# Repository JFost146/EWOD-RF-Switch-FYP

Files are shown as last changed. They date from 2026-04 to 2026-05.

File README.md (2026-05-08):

# Final Year Project  
## MEng Electrical and Electronic Engineering  
### Jack Foster — University of Birmingham

This repository contains the work completed for my final year MEng project at the University of Birmingham.

The project focuses on the development of an **electrowetting-on-dielectric (EWOD) circuit** designed to actuate a liquid droplet into a waveguide channel, where the liquid acts as part of an **RF switch**.

---

## Licence

This project is released under the **GNU General Public License v3.0**.

You are free to use, modify, and distribute the software and associated project files under the terms of the GPLv3. Any redistributed or modified versions must also comply with the GPLv3 terms.

A full copy of the licence is provided in the [`LICENSE`](license.txt) file.

Parts of this project are derived from or inspired by the GaudiLabs OpenDrop project and Nick de Smith’s Nixie high-voltage switching PSU. Please refer to the acknowledgements section for the original sources.

---

## Project Overview

The repository includes:

- KiCad circuit schematics and PCB design files
- Electrode board designs for EWOD testing
- Arduino-based control software
- RF switch simulation and measurement results
- Supporting notes and design references

---

## Circuit Basics

The `Circuit` folder contains the **KiCad 9.0** schematics, footprints, and manufacturing files used for the PCB.

The boards used in the project were manufactured by **JLCPCB** at approximately **£30 per board**. These boards used **ENIG plating** to optimise coupling between electrodes for EWOD operation. However, the design would likely still work with the cheaper **HASL** finish.

---

## Microcontroller and Software

The circuit was tested using a **Seeed Studio XIAO nRF52840**:

[Seeed Studio XIAO nRF52840 Documentation](https://wiki.seeedstudio.com/XIAO_BLE/)

The board should also be compatible with other microcontroller boards, as the controllable components operate using:

- `3V3`
- Clock signal
- Latch / chip-select signal

The controllable components are:

- Digital potentiometer
- High-voltage switch controller

The control code is written for **Arduino** and can be found in the `Software` folder.

---

## Board Setup and EWOD Testing

To use the board:

1. Snap off the electrode boards.
2. Solder all required components.
3. Connect an electrode board using fly-wires.
4. Add a hydrophobic oil layer to the electrodes.  
   - Silicone oil, **5 cSt**, is preferred.
5. Place a dielectric layer on top of the oil.  
   - Cling film can be used.
6. Add another oil layer on top of the dielectric.
7. Place the droplet above an electrode.
8. Observe the EWOD actuation.

---

## Notes and Testing Observations

- The potentiometer can be bypassed using the `R_pot_sub` resistor pads with either:
  - a `0 Ω` resistor, or
  - a solder bridge.

- Successful tests were proven at maximum voltage output, with the potentiometer set to `0 Ω`.

- EWOD actuation is likely to work at voltages of **200 V or higher**.

- The best EWOD results were achieved using the rectangular electrodes with droplets whose diameter was approximately equal to, or larger than, the width of one electrode.

- The board design is derived from the GaudiLabs OpenDrop board:  
  [GaudiLabs OpenDrop](https://www.gaudi.ch/OpenDrop/)

- The DC-DC converter design originates from Nick de Smith’s Nixie high-voltage switching PSU:  
  [Nick de Smith Nixie PSU](https://www.nick.desmith.net/Electronics/NixiePSU.html)

---

## Board Specifications

| Parameter | Value |
|---|---|
| Input voltage | 5 V |
| Input current at maximum output | 0.16 A |
| Theoretical input range | 4.5 V to 16 V |
| Electrode output voltage range | 50 V to 290 V |
| Electrode output current range | 2.3 µA to 13.2 µA |
| Number of electrode designs | 7 |
| Minimum tested standalone output from XIAO nRF52840 USB input  | 50 V |

---

## RF Switch Investigation

The `Liquid Switch Tests` results contain:

- CST simulation results
- VNA measurement results
- RF switch response data for different liquids

These results investigate the behaviour of an RF switch when closed using various liquid materials.

---

## Switch Link

Add switch link here.

---

## Acknowledgements

This project builds on open-source and publicly documented work from:

- [GaudiLabs OpenDrop](https://www.gaudi.ch/OpenDrop/)
- [Nick de Smith’s Nixie HV Switching PSU](https://www.nick.desmith.net/Electronics/NixiePSU.html)

---

## Author

**Jack Foster**  
MEng Electrical and Electronic Engineering  
University of Birmingham

## Project Supervisor

**Prof. Yi Wang**  
Department of Electronic, Electrical and Systems Engineering  
University of Birmingham

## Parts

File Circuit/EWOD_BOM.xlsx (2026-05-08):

Component | Designator | Value | Quantity | Price | Link | Total
478-KGM21NR71H104KTCT-ND | C2,C3 | 100nF | 2 | £0.07 | https://www.digikey.com/en/products/detail/kyocera-avx-components-corporation/KGM21NR71H104KT/564427?curr=gbp | £0.14
CL31A106KBHNNNE | C5 | 10uF | 1 | £0.27 | https://www.digikey.com/en/products/detail/samsung-electro-mechanics-america-inc/CL31A106KBHNNNE/3890962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 | £0.27
875105344010 | C1 | 100uF | 1 | £0.50 | https://www.digikey.com/en/products/detail/wurth-electronics-inc/875105344010/5147976?curr=gbp | £0.50
CDRH125/LDNP-101MC | L1 | 100uH | 1 | £0.82 | https://www.digikey.com/en/products/detail/sumida-america-inc/CDRH125-LDNP-101MC/1879027?curr=gbp | £0.82
RC0805JR-078K2L | R1 | 8k | 1 | £0.07 | https://www.digikey.com/en/products/detail/yageo/RC0805JR-078K2L/731320?curr=gbp | £0.07
CRCW080510K0FKEA | R5 | 10k | 1 | £0.07 | https://www.digikey.com/en/products/detail/vishay-dale/CRCW080510K0FKEA/1180897?curr=gbp | £0.07
RMCF1206JT22M0 | R3,R4,R8,R11 | 22M | 4 | £0.08 | https://www.digikey.com/en/products/detail/stackpole-electronics-inc/RMCF1206JT22M0/7906919?curr=gbp | £0.32
WSL2010R1000FEA18 | RSENSE1 | 0R100 | 1 | £0.76 | https://www.digikey.com/en/products/detail/vishay-dale/WSL2010R1000FEA18/713471?curr=gbp | £0.76
CC1812KKX7RYBB104 | C6 | 100nF, 250V | 1 | £0.63 | https://www.digikey.com/en/products/detail/yageo/CC1812KKX7RYBB104/8025658?curr=gbp | £0.63
KTR10EZPF1604 | R2 | 1M6 | 1 | £0.14 | https://www.digikey.com/en/products/detail/rohm-semiconductor/KTR10EZPF1604/1983963?curr=gbp | £0.14
AEH10104R7M250R | C4 | 4u7, 250V | 1 | £0.49 | https://www.digikey.com/en/products/detail/kyocera-avx-components-corporation/AEH10104R7M250R/21822541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 | £0.49
Xiao nRF52840 | Microcontroller1 | Conn_01x08 | 1 | £9.50 | https://www.google.com/aclk?co=1&cce=1&sig=AOD64_0QL7spy-WVdq1LHppbR7jBd_PUpQ&ctype=5&q=&adurl= | £9.50
625-ES2F-E3 | D1 | ES2F | 1 | £0.60 | https://www.digikey.com/en/products/detail/vishay-general-semiconductor-diodes-division/ES2F-E3-52T/1091575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 | £0.60
HV513WG-G | U2 | HV513 | 1 | £3.10 | https://www.digikey.com/en/products/detail/microchip-technology/HV513WG-G/4902648?curr=gbp | £3.10
MAX1771CPA | U1 | MAX1771ESA | 1 | £4.70 | https://www.digikey.co.uk/en/products/detail/analog-devices-inc-maxim-integrated/MAX1771CPA/1130157 | £4.70
MCP41050T-I/SN | U26 | MCP41050 | 1 | £1.40 | https://www.digikey.com/en/products/detail/microchip-technology/MCP41050T-I-SN/9923681?curr=gbp | £1.40
IRF644PBF-ND | T1 | TK560P60Y | 1 | £1.88 | https://uk.rs-online.com/web/p/mosfets/5429305?cm_mmc=aff2-_-uk-_-octopart-_-5429305-_-instock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 | £1.88
 |  |  |  |  |  | £25.39
 |  |  |  |  | After VAT | £30.47
PCB (per board with delivery) |  |  | 1 | £28.00 | https://jlcpcb.com | £58.47

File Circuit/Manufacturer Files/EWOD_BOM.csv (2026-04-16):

Comment | Qty | Designator | Footprint | LCSC Part Number | Manufacturer UK | Manufacturer Part Number
0 Ohms | 1 | R_pot_sub1 | - | -
100nF | 2 | C2,C3 | 0805 | C38141 | Digikey | 478-KGM21NR71H104KTCT-ND
10uF | 1 | C5 | 1206 | C1849 | Digikey | CL31A106KBHNNNE
100uF | 1 | C1 | Capacitor_SMD:CP_Elec_6.3x5.4_Nichicon | C2161820 | Digikey | 875105344010
100uH | 1 | L1 | CDRH125101MC | C212268 | Digikey | CDRH125/LDNP-101MC
8k | 1 | R1 | 0805 | C413197 | Digikey | P0805Z8001FNT
10k | 1 | R5 | 0805 | C22356686 | Digikey | CRCW080510K0FKEA
22M, 250 V | 4 | R3,R4,R8,R11 | 1206 | C41755 | Digikey | RMCF1206JT22M0
0R100, 1.5 A | 1 | RSENSE1 | 2010 | C159215 | Digikey | WSL2010R1000FEA18
100nF, 250V | 1 | C6 | 1812 | C304034 | Digikey | CC1812KKX7RYBB104
1M6, 250 V | 1 | R2 | 0805 | C723463 | Digikey | KTR10EZPF1604
4u7, 250V | 1 | C4 | Capacitor_SMD:CP_Elec_10x10.5 | C5549292 | Digikey | AEH10104R7M250R
Conn_01x02 | 7 | J1,J2,J8,J9,J10,J11,J12 | - | -
Conn_01x02 | 1 | J7 | - | -
Conn_01x07 | 2 | Power_In1,Power_In2 | - | -
Conn_01x08 | 1 | Microcontroller1 | - | -
Electrode 2 | 5 | U4,U11,U12,U13,U14 | - | -
Electrode 2 | 4 | U9,U23,U24,U25 | - | -
Electrode 2 | 4 | U15,U16,U17,U18 | - | -
Electrode 2 | 4 | U19,U20,U21,U22 | - | -
Electrode 2 | 4 | U27,U28,U29,U30 | - | -
Electrode 2 | 4 | U31,U32,U33,U34 | - | -
Electrode 3 | 1 | U5 | - | -
Electrode 6 | 1 | U8 | - | -
Electrode 8 | 1 | U10 | - | -
Diode ES2F, 300 V 2 A | 1 | D1 | DIOM5436X244N | C222525 | Mouser | 625-ES2F-E3
Ground Ref | 1 | U7 | - | -
HV513 | 1 | U2 | Package_SO:SOP-24_7.5x15.4mm_P1.27mm | C631624 | Digikey | HV513WG-G
MAX1771ESA | 1 | U1 | PowerIntegrations_PDIP-8 | C3191535 | RS | MAX1771CPA
MCP41050 | 1 | U26 | Package_SO:SOIC-8_3.9x4.9mm_P1.27mm | C623335 | Digikey | MCP41050T-I/SN
MountingHole | 14 | H8,H9,H10,H11,H12,H13,H14,H15,H16,H17,H18,H19,H20,H21 | - | -
MouseBites | 7 | H1,H2,H3,H4,H5,H6,H7 | - | -
On Pad | 1 | U6 | - | -
Power Pad | 1 | U3 | - | -
SW_SPDT | 1 | SW2 | - | -
Test Pad | 1 | U35 | - | -
TK560P60Y | 1 | T1 | Package_TO_SOT_THT:TO-220-3_Vertical | C469331 | Digikey | IRF644PBF-ND

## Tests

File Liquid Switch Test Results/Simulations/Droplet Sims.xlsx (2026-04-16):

Freq (GHz) | EGaIn, S11 | EGaIn, S21 | NaOH 0.1M, S11 | NaOH 0.1M, S21 | NaOH 0.5M, S11 | NaOH 0.5M, S21 | Water, S11 | Water, S21 | Closed, S11 | Closed, S21
0.01 | -0.000376655211 | -82.24116738 | -13.99641831 | -1.930987513 | -4.393044365 | -8.025012248 | -13.59804848 | -2.033075431 | -92.21690954 | -0.0001995270421
0.01999 | -0.000659199666 | -76.52338692 | -13.98466043 | -1.93139531 | -4.393074722 | -8.025206264 | -13.58557533 | -2.033878227 | -90.51732778 | -0.00081709787
0.02998 | -0.000920427591 | -73.12841517 | -13.96338379 | -1.932486234 | -4.392912318 | -8.025519188 | -13.56503447 | -2.035115462 | -89.09809974 | -0.001413145426
0.03997 | -0.001170434871 | -70.70007646 | -13.93341964 | -1.934063492 | -4.392603916 | -8.025895763 | -13.53650574 | -2.036782243 | -87.89210273 | -0.001988137113
0.04996 | -0.001413237737 | -68.80647088 | -13.8951471 | -1.936080485 | -4.3921554 | -8.026329239 | -13.50019209 | -2.038872466 | -86.85141026 | -0.002542538794
0.05995 | -0.001650924175 | -67.25332851 | -13.8489079 | -1.938515929 | -4.391568397 | -8.026817909 | -13.45635354 | -2.041378785 | -85.94190356 | -0.003076814639
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

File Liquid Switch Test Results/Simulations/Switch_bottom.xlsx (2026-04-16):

Freq (GHz) | GaAs, S11 | GaAs, S21 | NaOH 0.1M, S11 | NaOH 0.1M, S21 | Water, S11 | Water, S21 | Water Distilled, S11 | Water Distilled, S21 | Closed, S11 | Closed, S21
0.01 | -54.93709802 | -0.0002809672602 | -11.62602498 | -2.64166928 | -11.25891555 | -2.776195634 | -39.72329924 | -0.0005303563871 | -75.41402262 | -0.0001983249939
0.01999 | -49.27840449 | -0.0005304665452 | -11.61680169 | -2.642487383 | -11.25361269 | -2.776760838 | -33.71191424 | -0.00169013826 | -72.93053185 | 0
0.02998 | -45.83041074 | -0.000810645648 | -11.60136426 | -2.643738667 | -11.2424969 | -2.777790795 | -30.19526843 | -0.003797075019 | -70.33123351 | 0
0.03997 | -43.35782394 | -0.001121263951 | -11.57978102 | -2.645423073 | -11.22557044 | -2.779285651 | -27.70139447 | -0.006849035442 | -68.11174618 | 0
0.04996 | -41.43117539 | -0.001462085401 | -11.55215091 | -2.647540351 | -11.202867 | -2.781245308 | -25.76855317 | -0.01084318547 | -66.2546239 | -9.643274666e-16
0.05995 | -39.85309248 | -0.001832878575 | -11.51860199 | -2.650090057 | -11.17445114 | -2.783669425 | -24.19098825 | -0.01577599514 | -64.67918868 | 0
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

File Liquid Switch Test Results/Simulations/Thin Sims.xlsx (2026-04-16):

Freq (GHz) | EGaIn, S11 | EGaIn, S21 | NaOH 0.1M, S11 | NaOH 0.1M, S21 | NaOH 0.5M, S11 | NaOH 0.5M, S21 | Water, S11 | Water, S21 | Closed, S11 | Closed, S21
0.01 | -0.0002127651725 | -83.34633011 | -14.18135866 | -1.888299912 | -4.484407936 | -7.888869163 | -13.79624295 | -1.986299744 | -92.21690954 | -0.0001995270421
0.01999 | -0.0004240735189 | -77.50630795 | -14.17187284 | -1.888804342 | -4.484445048 | -7.889098277 | -13.78676481 | -1.986824623 | -90.51732778 | -0.00081709787
0.02998 | -0.0006346349216 | -74.11918099 | -14.15561943 | -1.889559699 | -4.484364335 | -7.889373459 | -13.77110999 | -1.987614254 | -89.09809974 | -0.001413145426
0.03997 | -0.0008446135549 | -71.73188525 | -14.13286771 | -1.890564659 | -4.484176411 | -7.889687112 | -13.74927227 | -1.988665417 | -87.89210273 | -0.001988137113
0.04996 | -0.001054106988 | -69.89039533 | -14.10375809 | -1.891818957 | -4.483882651 | -7.890038297 | -13.72134602 | -1.98997739 | -86.85141026 | -0.002542538794
0.05995 | -0.001263181905 | -68.39298722 | -14.06843898 | -1.893322169 | -4.483483483 | -7.890426767 | -13.68745967 | -1.991549689 | -85.94190356 | -0.003076814639
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

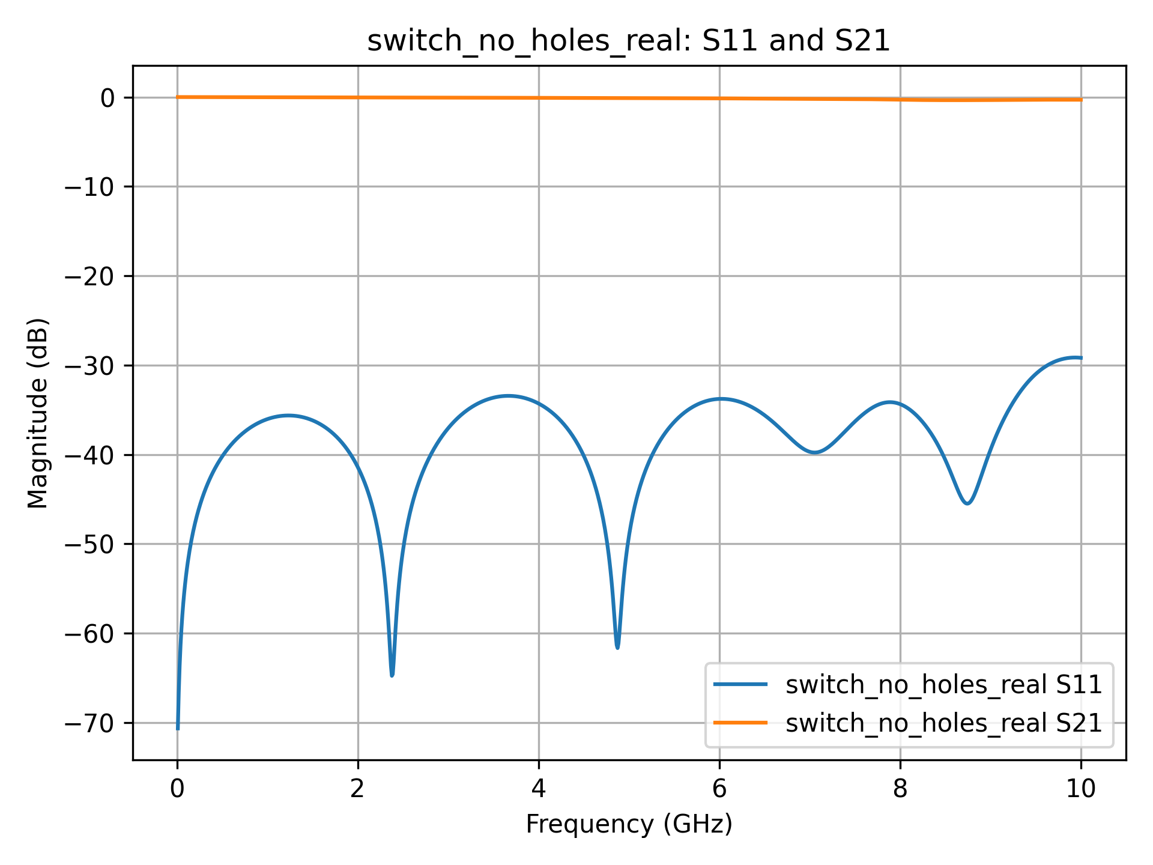
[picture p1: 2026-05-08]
Liquid Switch Test Results/Simulations/Figures/switch_no_holes_real_S11_S21_plot.png

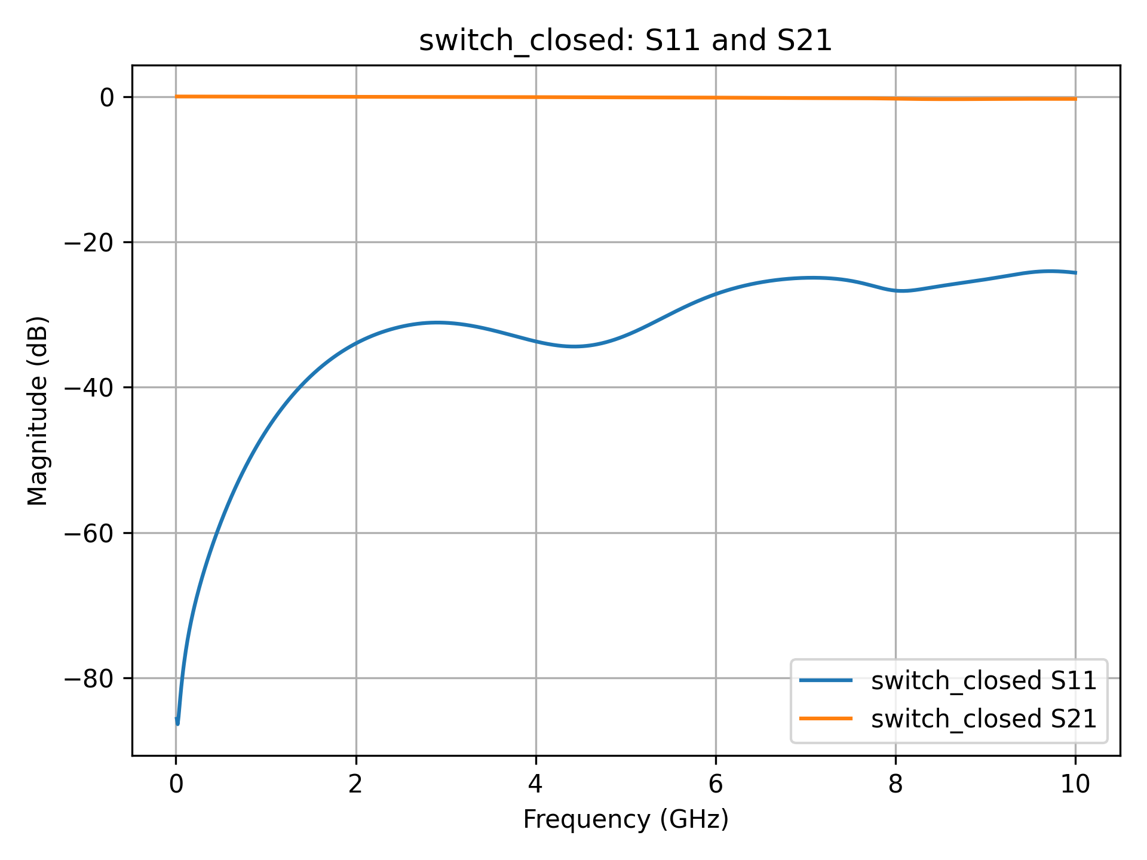
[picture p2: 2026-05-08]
Liquid Switch Test Results/Simulations/Figures/switch_closed_S11_S21_plot.png

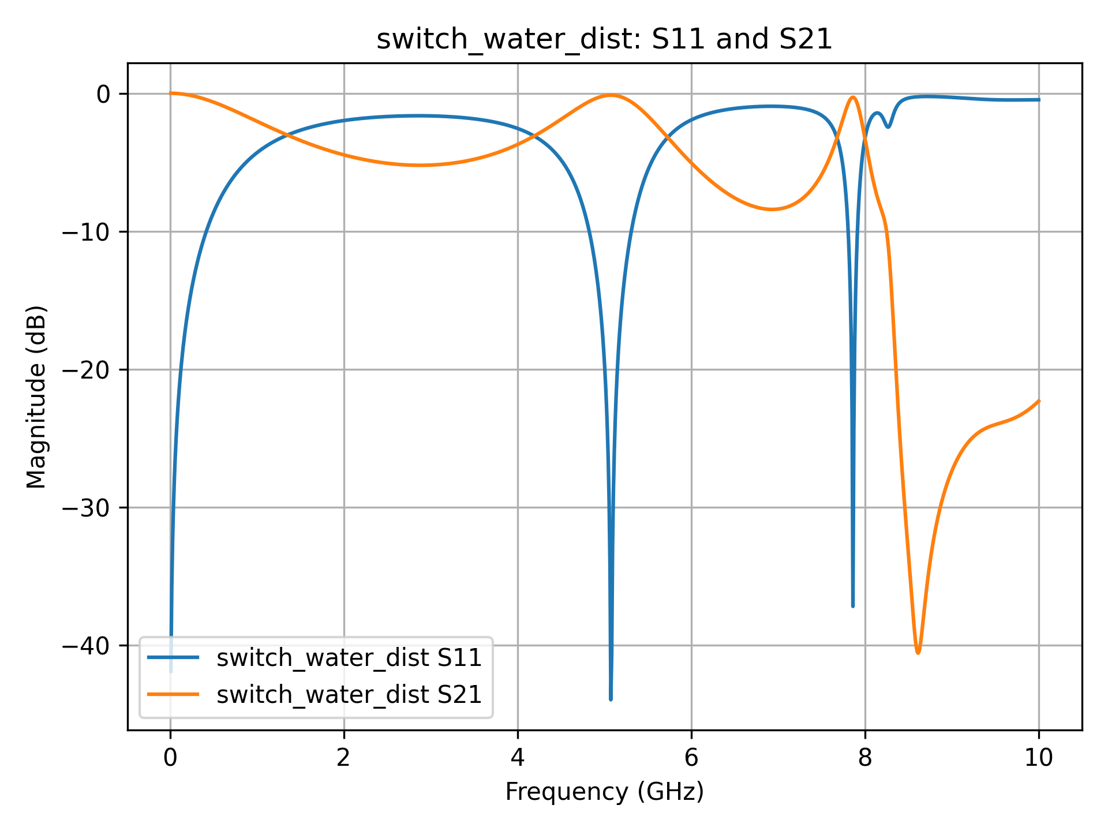
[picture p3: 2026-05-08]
Liquid Switch Test Results/Simulations/Figures/switch_water_dist_S11_S21_plot.png

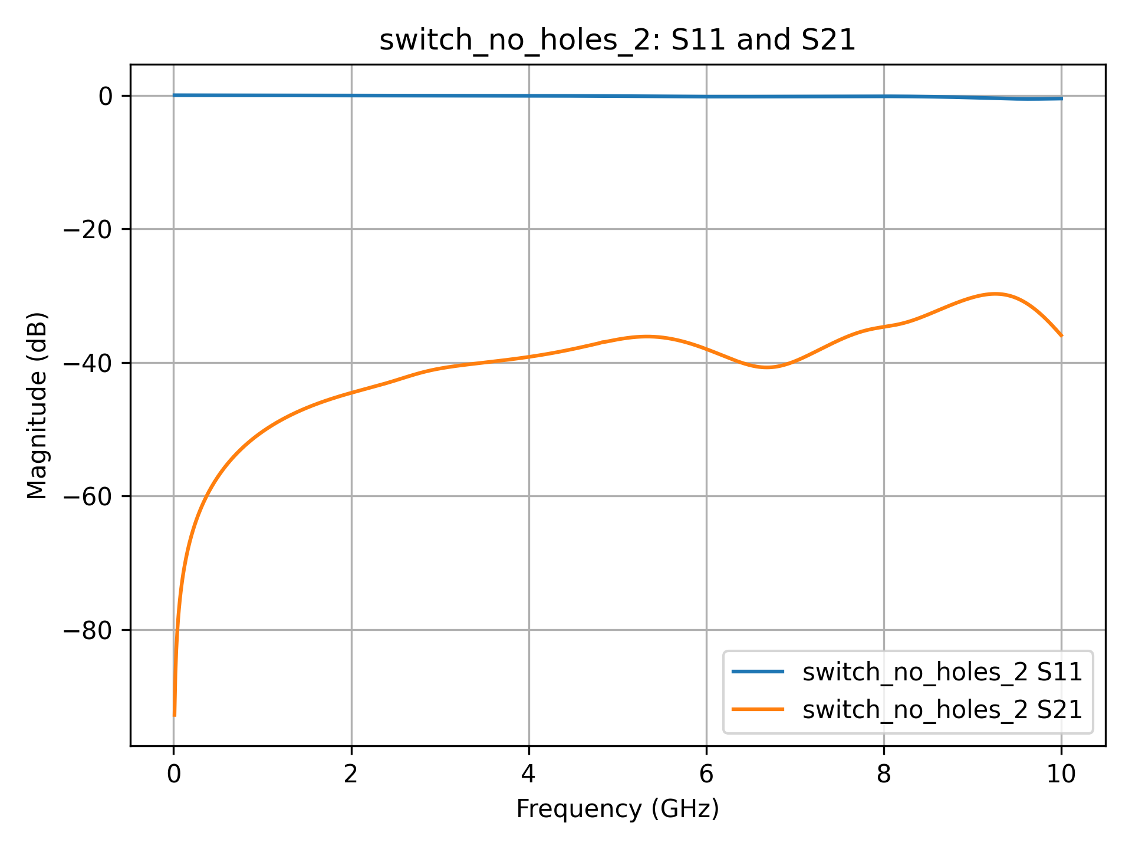
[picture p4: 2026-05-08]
Liquid Switch Test Results/Simulations/Figures/switch_no_holes_2_S11_S21_plot.png

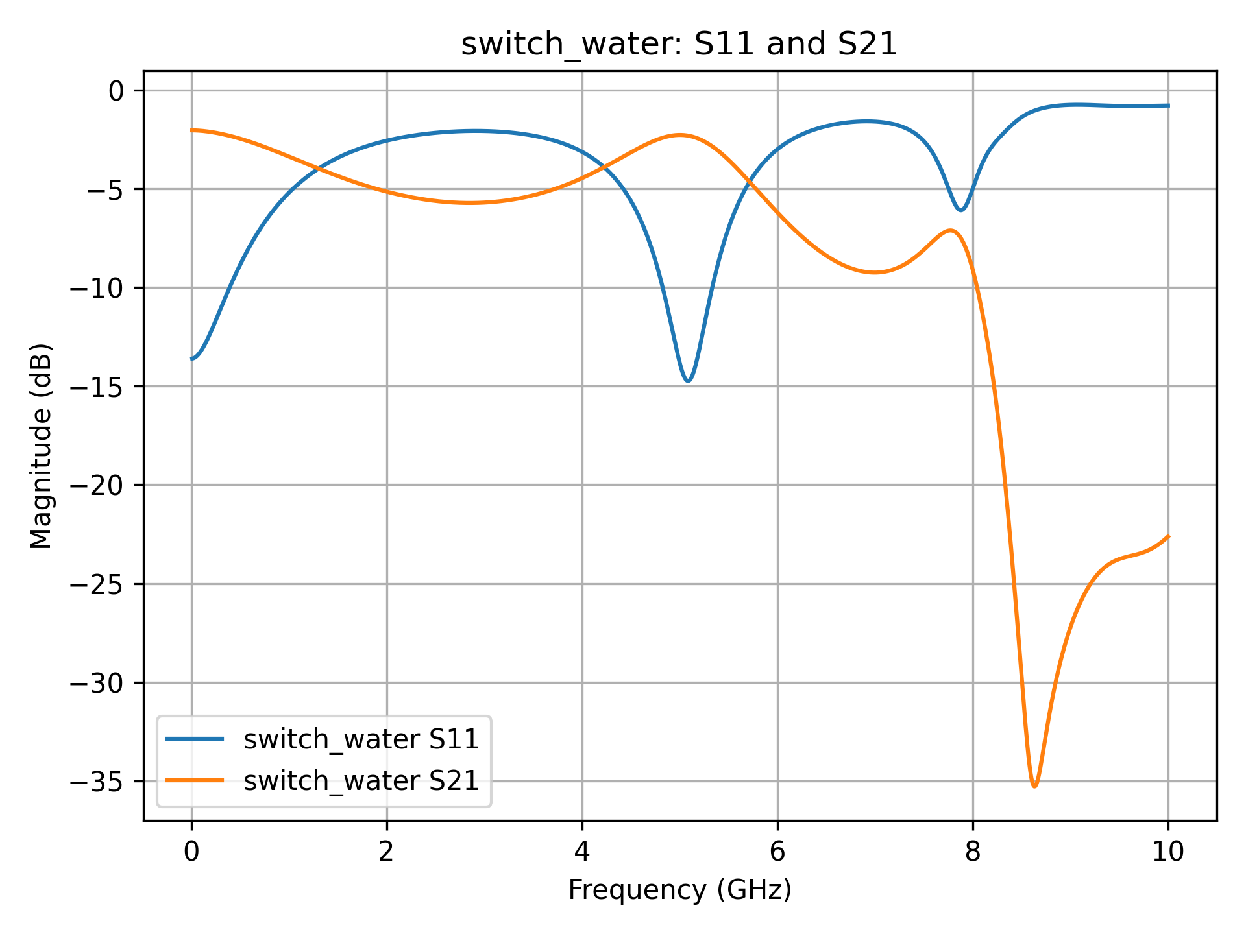
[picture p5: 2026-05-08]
Liquid Switch Test Results/Simulations/Figures/switch_water_S11_S21_plot.png

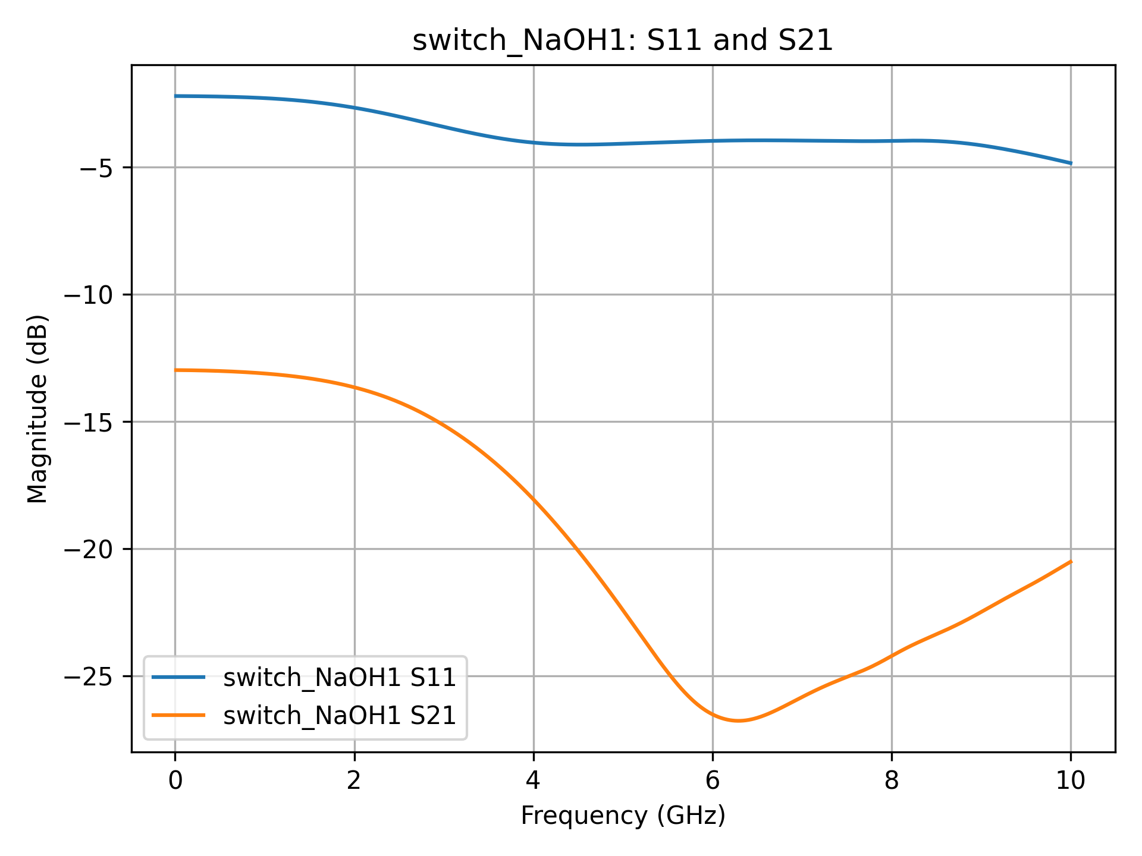
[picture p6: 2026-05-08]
Liquid Switch Test Results/Simulations/Figures/switch_NaOH1_S11_S21_plot.png

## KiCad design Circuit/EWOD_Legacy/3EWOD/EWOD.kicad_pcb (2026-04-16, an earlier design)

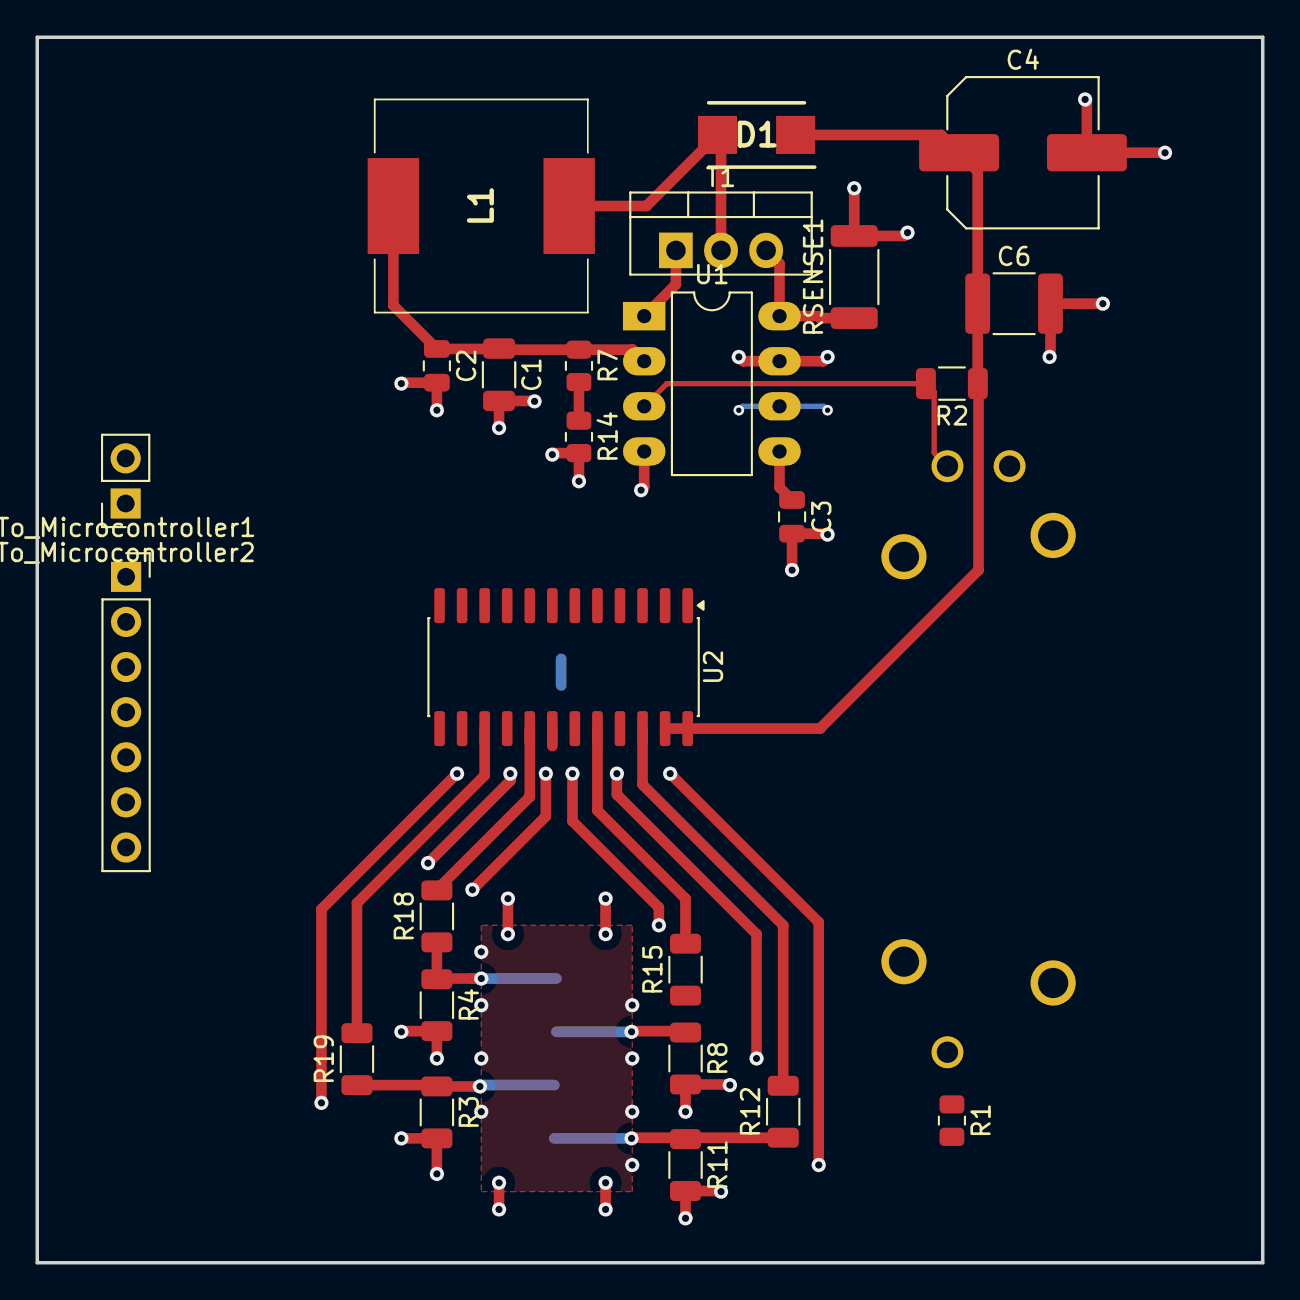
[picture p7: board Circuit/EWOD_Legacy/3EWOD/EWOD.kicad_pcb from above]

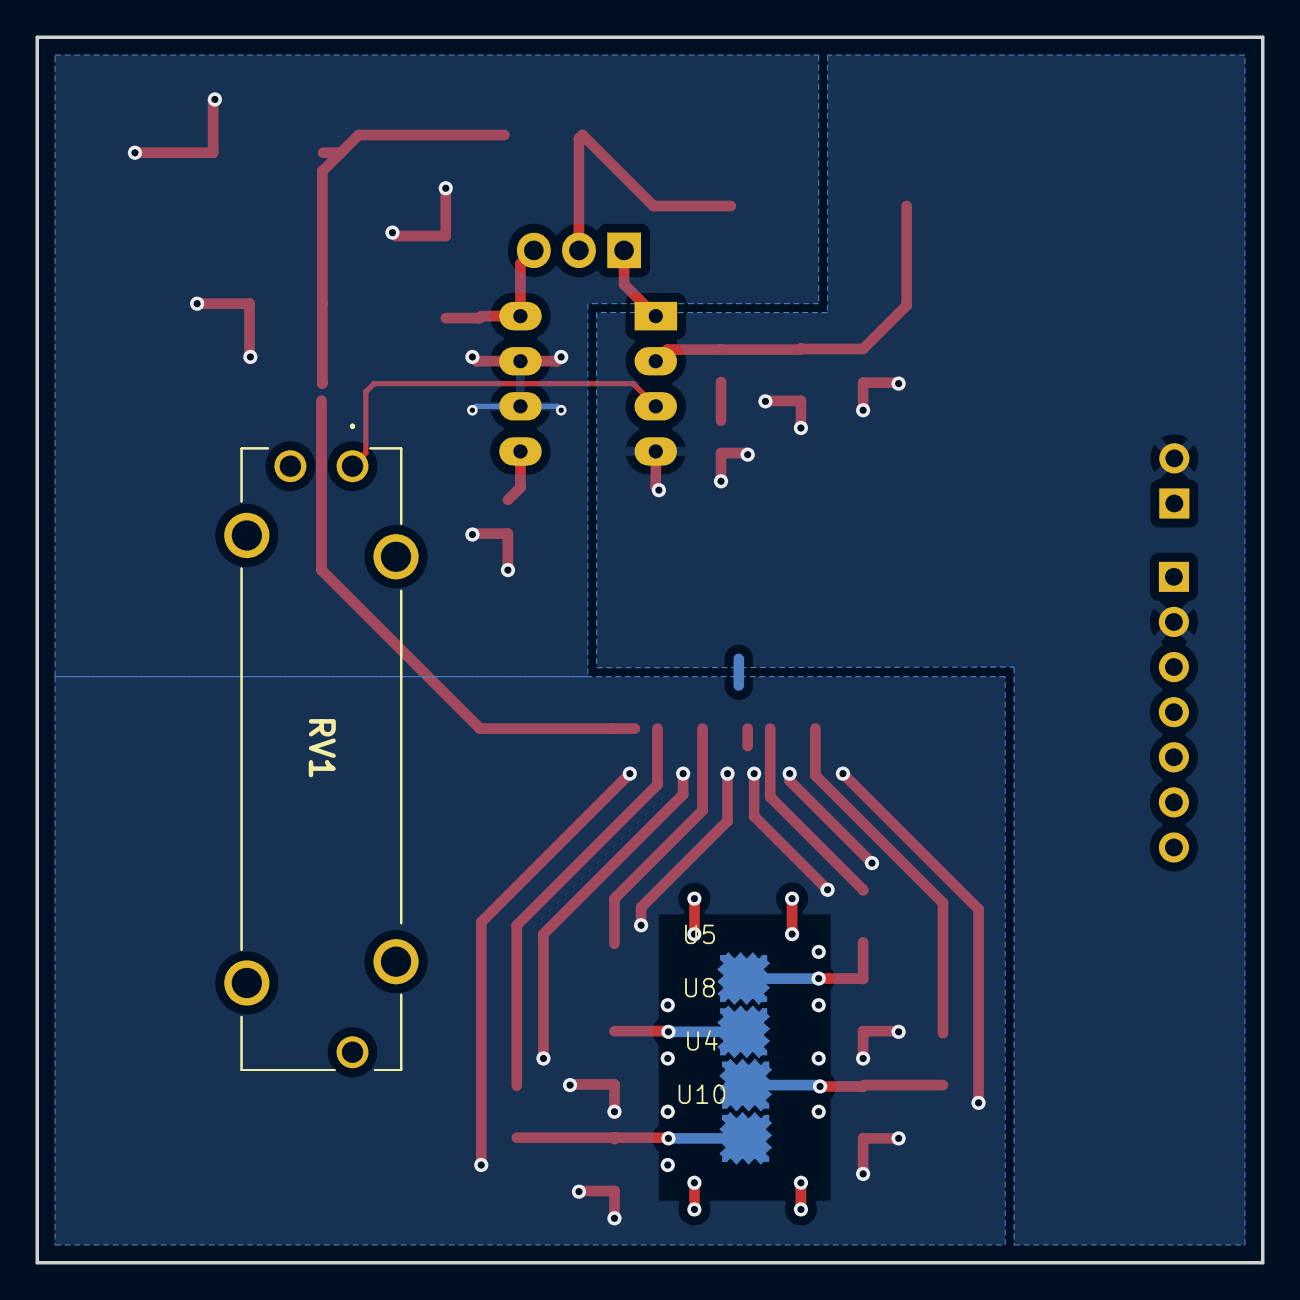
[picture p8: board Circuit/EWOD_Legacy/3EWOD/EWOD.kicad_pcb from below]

Board: 2 copper layers, 69.0 x 69.0 mm, 30 parts (5 on the bottom side), 24 nets.

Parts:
C1: 100uF, 6.3V; C_1206_3216Metric
C2, C3: 100nF; C_0805_2012Metric
C4: 4u7, 250V; C_Elec_8x10.2
C6: 100nF, 250V; C_1812_4532Metric
D1: ES2F; DIOM5436X244N
L1: 100uH; CDRH125101MC
R1: ak; R_0805_2012Metric
R2: 1M5; R_1206_3216Metric
R3, R4, R8, R11: 22M; R_1206_3216Metric
R7: 6.8k; R_0805_2012Metric
R12, R15, R18, R19: 200; R_1206_3216Metric
R14: 10k; R_0805_2012Metric
RSENSE1: 0R1; R_2010_5025Metric
RV1: R_Potentiometer; PTA20432015CPB503
T1: TK560P60Y; TO-220-3_Vertical
To_Microcontroller1: Conn_01x07; PinSocket_1x07_P2.54mm_Vertical
To_Microcontroller2: Conn_01x07; PinSocket_1x02_P2.54mm_Vertical
U1: MAX1771ESA; PowerIntegrations_PDIP-8
U2: HV513; SO-24_5.3x15mm_P1.27mm
U4: Electrode 2; Electrode
U5: Electrode 3; Electrode
U8: Electrode 6; Electrode
U10: Electrode 8; Electrode

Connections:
GND: C1.2, C2.2, C3.2, C4.2, C6.2, R1.2, R3.2, R4.2, R8.2, R11.2, R14.2, RSENSE1.2, To_Microcontroller1.2, To_Microcontroller2.2, U1.4 (SHDN), U1.6 (AGND), U1.7 (GND), U2.11 (LVGND), U2.13 (HVGND), U2.14 (HVGND)
unnamed: R1.1, RV1.3
unnamed: R11.1, R12.1, U10.1
unnamed: R8.1, R15.1, U8.1
unnamed: R4.1, R18.1, U5.1
unnamed: R3.1, R19.1, U4.1
unnamed: D1.2, L1.2, T1.2 (D)
unnamed: T1.1 (G), U1.1 (EXT)
unnamed: RSENSE1.1, T1.3 (S), U1.8 (CS)
unnamed: To_Microcontroller1.1, U2.2 (VDD_logic_supply)
unnamed: To_Microcontroller1.3, U2.4 (BL)
unnamed: To_Microcontroller1.4, U2.5 (POL)
unnamed: To_Microcontroller1.5, U2.6 (CLK)
unnamed: To_Microcontroller1.6, U2.7 (LE)
unnamed: To_Microcontroller1.7, U2.10 (DIN)
unnamed: R2.2, RV1.1, U1.3 (FB)
unnamed: C3.1, U1.5 (REF)
unnamed: C1.1, C2.1, L1.1, R7.1, U1.2 (VCC)
unnamed: R19.2, U2.15 (HVOUT1)
unnamed: R18.2, U2.17 (HVOUT3)
unnamed: R15.2, U2.20 (HVOUT6)
unnamed: R12.2, U2.22 (HVOUT8)
V_HV: C4.1, C6.1, D1.1, R2.1, U2.23 (HVpp), U2.24 (HVpp)
V_In_SENS: R7.2, R14.1

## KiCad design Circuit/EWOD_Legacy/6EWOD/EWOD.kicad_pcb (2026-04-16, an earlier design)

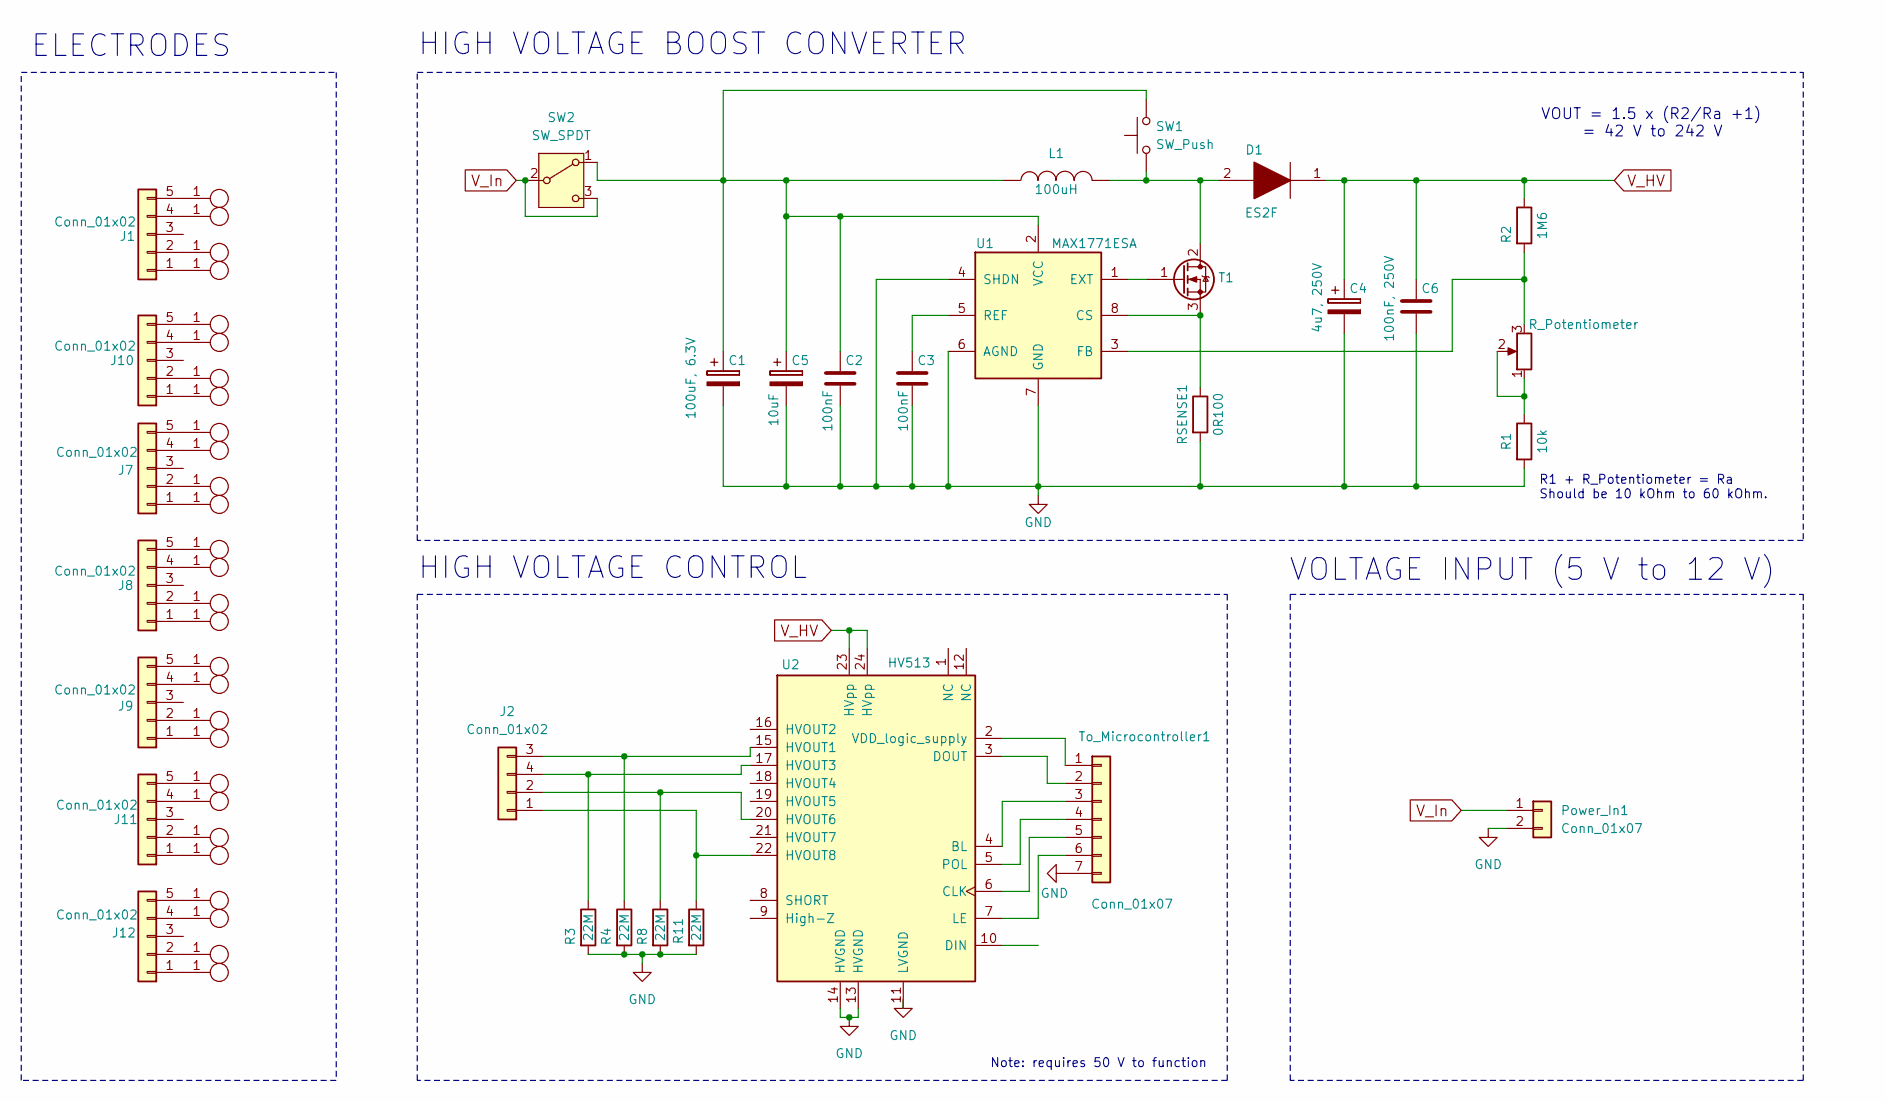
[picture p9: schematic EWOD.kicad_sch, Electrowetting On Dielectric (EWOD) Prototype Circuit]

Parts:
C1: 100uF, 6.3V; CP_Elec_6.3x5.4_Nichicon
C2, C3: 100nF; C_0805_2012Metric
C4: 4u7, 250V; CP_Elec_10x10.5
C5: 10uF; C_1206_3216Metric
C6: 100nF, 250V; C_1812_4532Metric
D1: ES2F; DIOM5436X244N; Manufacturer_Part_Number ES2F-E3/52T; Mouser Part Number 625-ES2F-E3
J1, J7, J8, J9, J10, J11, J12: Conn_01x02; Zhaoxing_VH_ZX-VH3.96-5PLT_1x05-1MP_P3.96mm_Vertical_0
J2: Conn_01x02; PinSocket_1x04_P2.54mm_Vertical
L1: 100uH; CDRH125101MC
Power_In1: Conn_01x07; PinSocket_1x02_P2.54mm_Vertical
R1: 10k; R_0805_2012Metric
R2: 1M6; R_1206_3216Metric
R3, R4, R8, R11: 22M; R_1206_3216Metric
RSENSE1: 0R100; R_2010_5025Metric
RV1: R_Potentiometer; SOT-363_SC-70-6_Handsoldering
SW1: SW_Push
SW2: SW_SPDT; PinHeader_1x03_P2.54mm_Vertical
T1: TK560P60Y; TO-220-3_Vertical
To_Microcontroller1: Conn_01x07; PinSocket_1x07_P2.54mm_Vertical
U1: MAX1771ESA; PowerIntegrations_PDIP-8
U2: HV513; SOP-24_7.5x15.4mm_P1.27mm
U4: Electrode 2; Electrode
U5: Electrode 3; Electrode
U8: Electrode 6; Electrode
U10: Electrode 8; Electrode
U11, U12, U13, U14: Electrode 2; Electrode_2_1
U15, U16, U17, U18: Electrode 2; Electrode_3
U19, U20, U21, U22: Electrode 2; Electrode_4
U23, U24, U25, U26: Electrode 2; Electrode_2
U27, U28, U29, U30: Electrode 2; Electrode_5
U31, U32, U33, U34: Electrode 2; Electrode_6

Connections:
GND: C1.2, C2.2, C3.2, C4.2, C5.2, C6.2, Power_In1.2, R1.2, R3.2, R4.2, R8.2, R11.2, RSENSE1.2, To_Microcontroller1.7, U1.4 (SHDN), U1.6 (AGND), U1.7 (GND), U2.11 (LVGND), U2.13 (HVGND), U2.14 (HVGND)
unnamed: J1.1, U10.1
unnamed: J1.2, U8.1
unnamed: J1.4, U5.1
unnamed: J1.5, U4.1
unnamed: J2.1, R11.1, U2.22 (HVOUT8)
unnamed: J2.2, R8.1, U2.20 (HVOUT6)
unnamed: J2.4 (Pin_3), R3.1, U2.17 (HVOUT3)
unnamed: J2.3 (Pin_4), R4.1, U2.15 (HVOUT1)
unnamed: J7.1, U14.1
unnamed: J7.2, U13.1
unnamed: J7.4, U12.1
unnamed: J7.5, U11.1
unnamed: J8.1, U18.1
unnamed: J8.2, U17.1
unnamed: J8.4, U16.1
unnamed: J8.5, U15.1
unnamed: J9.1, U22.1
unnamed: J9.2, U21.1
unnamed: J9.4, U20.1
unnamed: J9.5, U19.1
unnamed: J10.1, U26.1
unnamed: J10.2, U25.1
unnamed: J10.4, U24.1
unnamed: J10.5, U23.1
unnamed: J11.1, U30.1
unnamed: J11.2, U29.1
unnamed: J11.4, U28.1
unnamed: J11.5, U27.1
unnamed: J12.1, U34.1
unnamed: J12.2, U33.1
unnamed: J12.4, U32.1
unnamed: J12.5, U31.1
unnamed: R1.1, RV1.1, RV1.2
unnamed: C1.1, C2.1, C5.1, L1.1, SW1.2, SW2.1 (A), U1.2 (VCC)
unnamed: D1.2, L1.2, SW1.1, T1.2 (D)
unnamed: T1.1 (G), U1.1 (EXT)
unnamed: RSENSE1.1, T1.3 (S), U1.8 (CS)
unnamed: To_Microcontroller1.1, U2.2 (VDD_logic_supply)
unnamed: To_Microcontroller1.2, U2.3 (DOUT)
unnamed: To_Microcontroller1.3, U2.4 (BL)
unnamed: To_Microcontroller1.4, U2.5 (POL)
unnamed: To_Microcontroller1.5, U2.6 (CLK)
unnamed: To_Microcontroller1.6, U2.7 (LE)
unnamed: R2.2, RV1.3, U1.3 (FB)
unnamed: C3.1, U1.5 (REF)
V_HV: C4.1, C6.1, D1.1, R2.1, U2.23 (HVpp), U2.24 (HVpp)
V_In: Power_In1.1, SW2.2 (B), SW2.3 (C)

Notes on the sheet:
HIGH VOLTAGE CONTROL
Note: requires 50 V to function
ELECTRODES
HIGH VOLTAGE BOOST CONVERTER
R1 + R_Potentiometer = Ra Should be 10 kOhm to 60 kOhm.
VOUT = 1.5 x (R2/Ra +1) = 42 V to 242 V
VOLTAGE INPUT (5 V to 12 V)

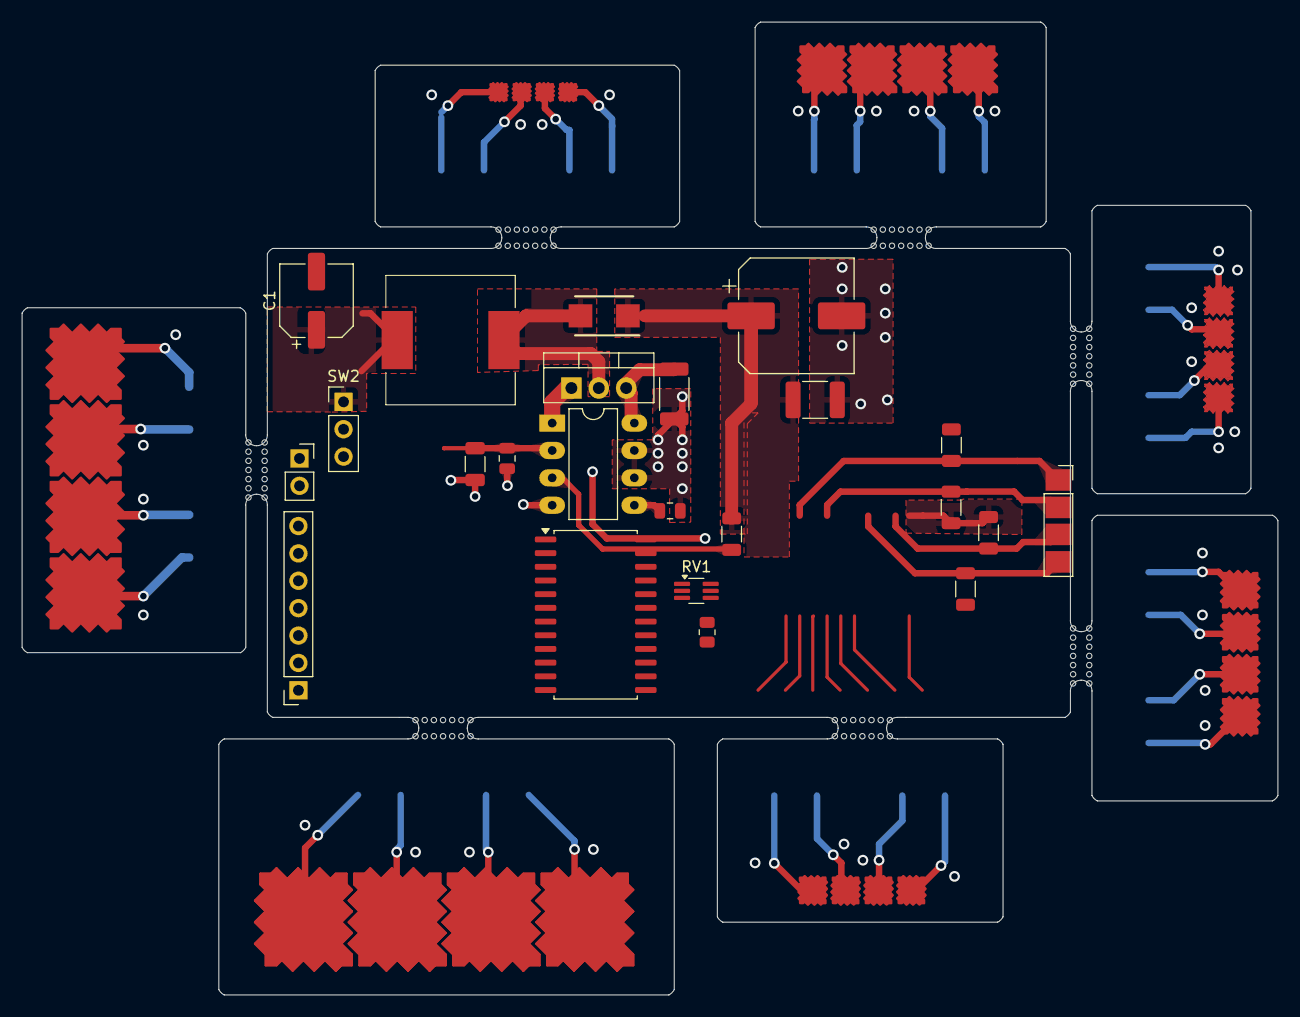
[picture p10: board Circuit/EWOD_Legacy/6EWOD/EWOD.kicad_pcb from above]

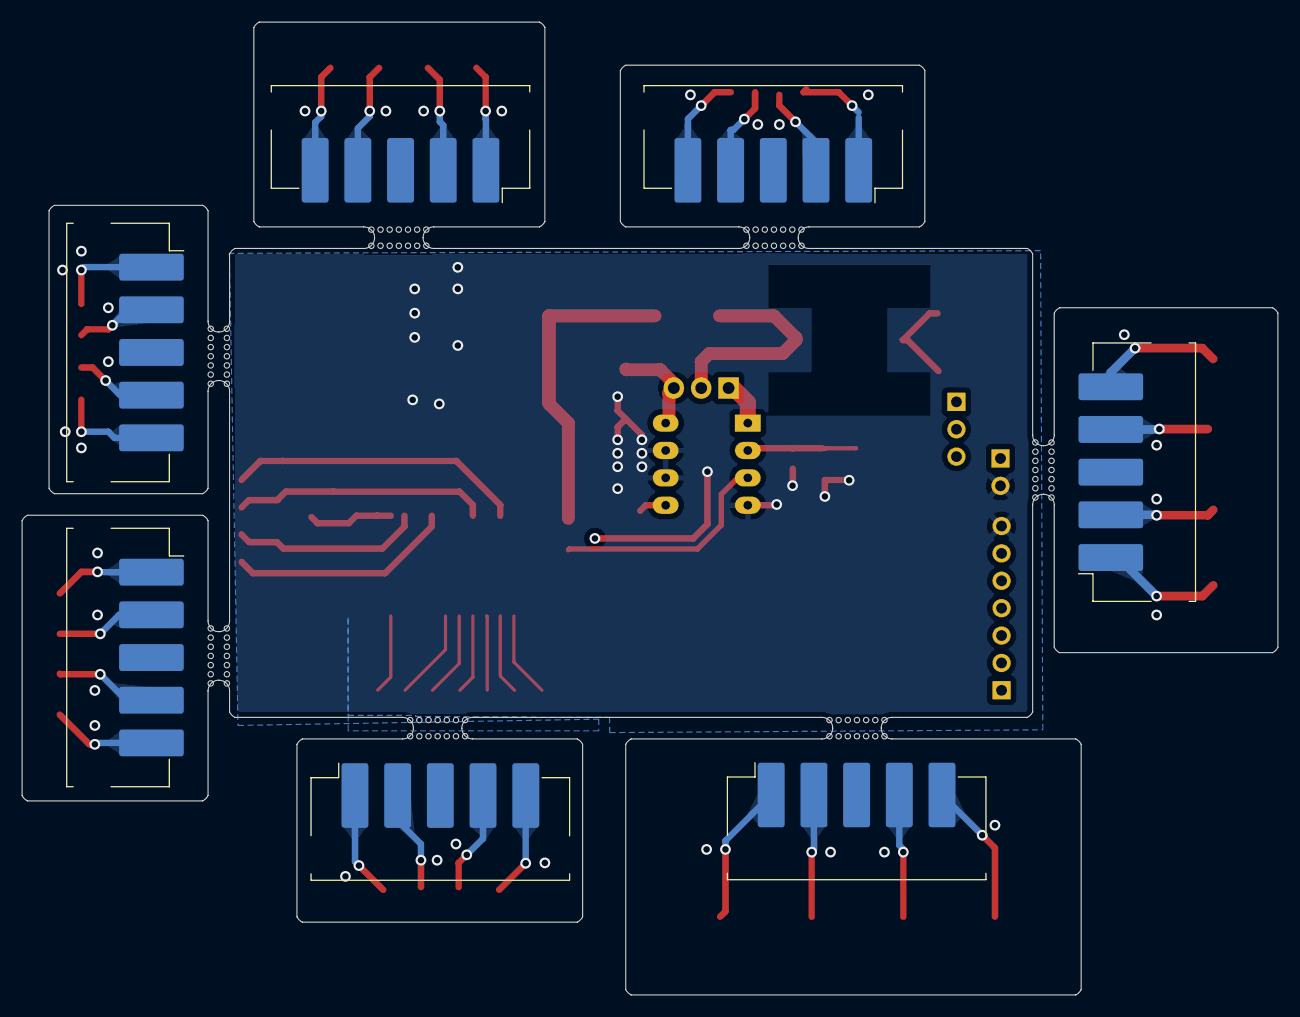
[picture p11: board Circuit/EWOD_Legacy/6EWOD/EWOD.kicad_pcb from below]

Board: 2 copper layers, 116.5 x 90.2 mm, 72 parts (7 on the bottom side), 48 nets.

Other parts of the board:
J3, J3#2, J3#3, J3#4, J3#5, J3#6, J3#7, J3#8, J3#9, J3#10, J5, J5#2, J5#3, J5#4: Screw_Terminal_01x01; MouseBite-Part_2.0x4.5mm_outset_D0.5mm_P0.85mm_7h

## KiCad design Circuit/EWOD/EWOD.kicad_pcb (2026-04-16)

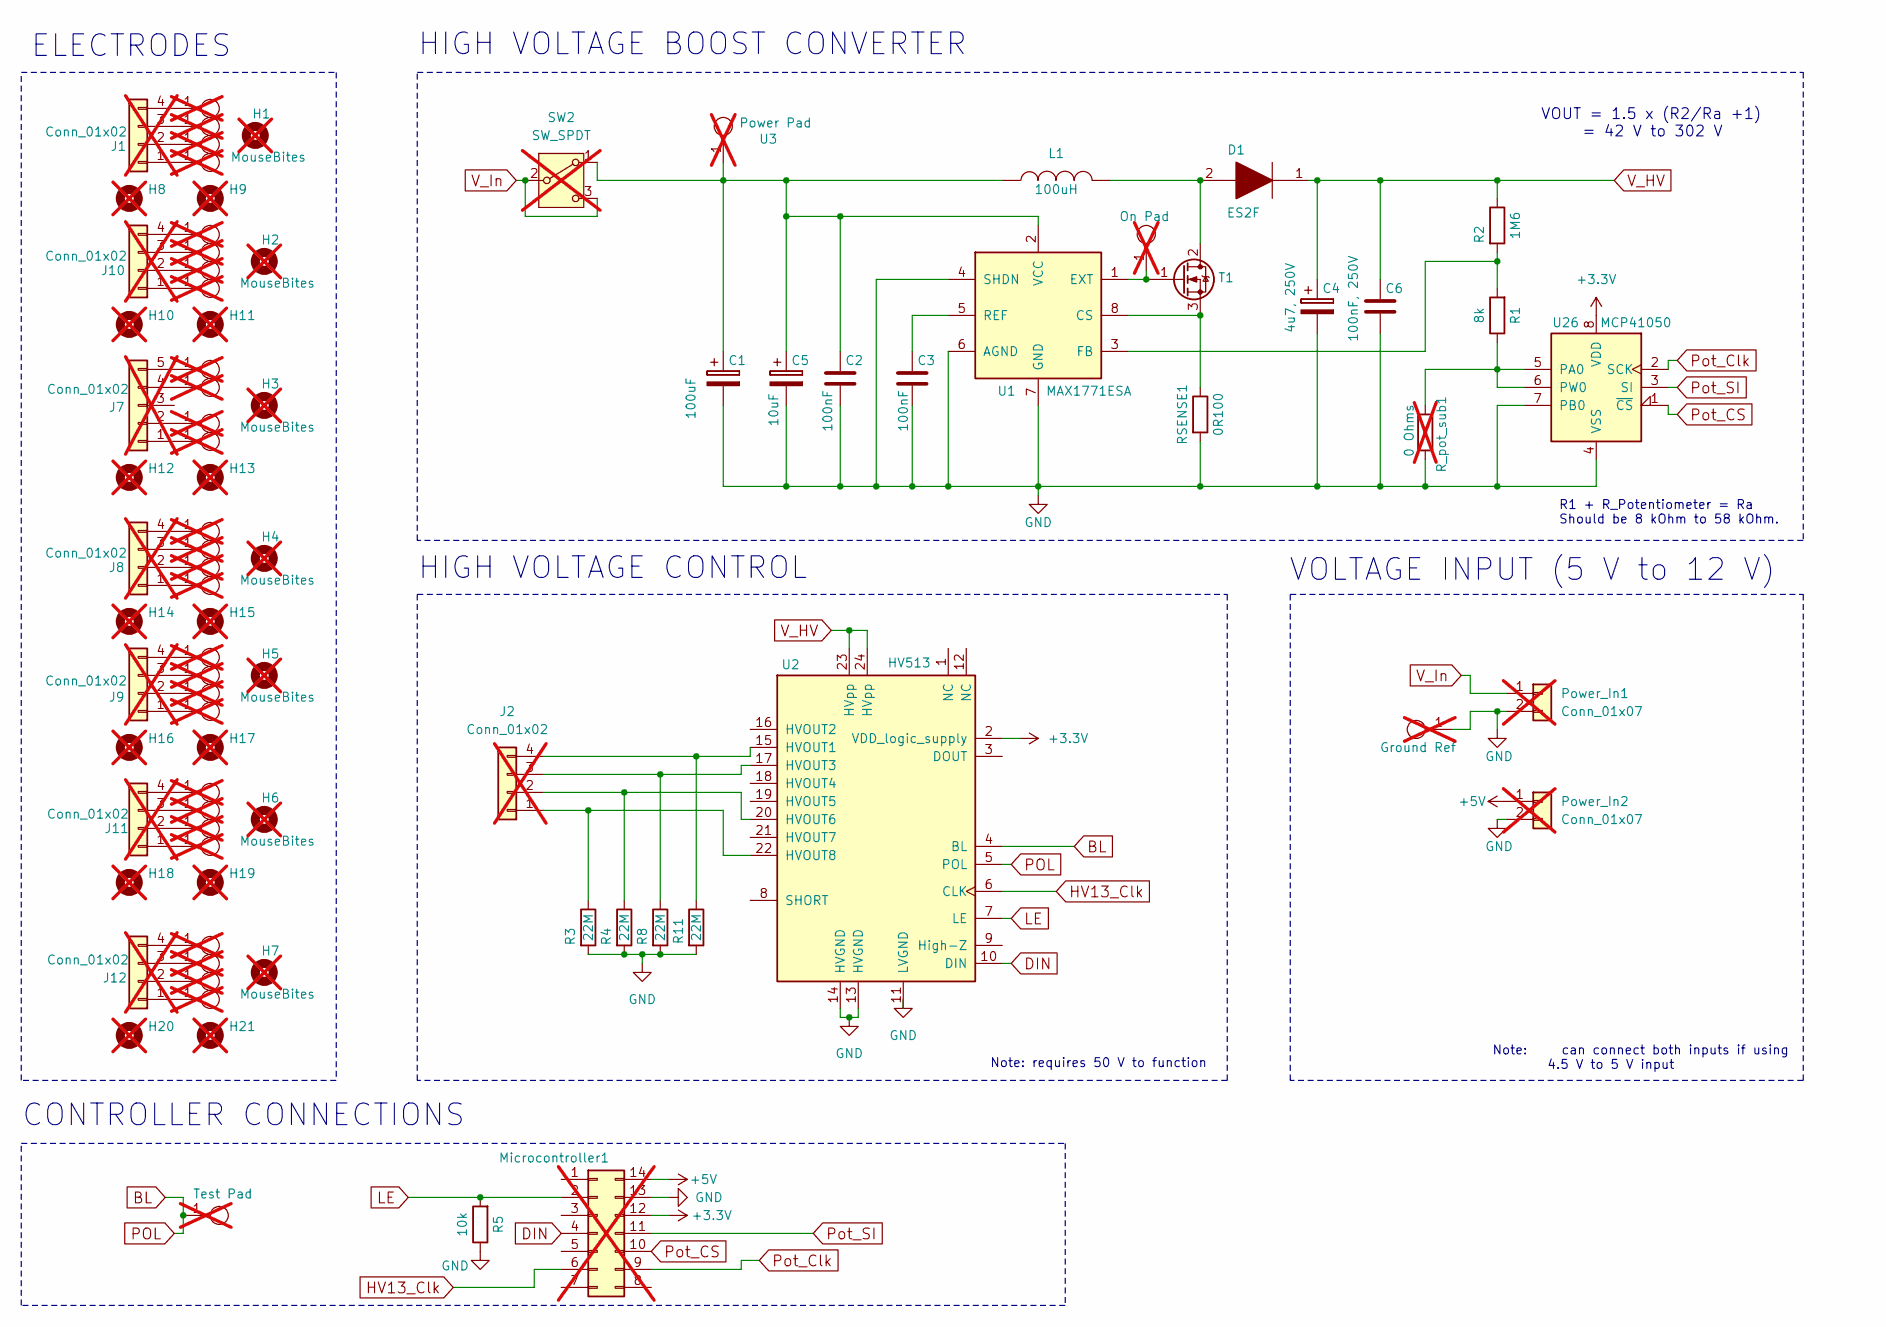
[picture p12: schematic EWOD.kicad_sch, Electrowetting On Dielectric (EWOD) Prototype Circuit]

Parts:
C1: 100uF; CP_Elec_6.3x5.4_Nichicon; Manufacturer_Part_Number 875105344010
C2, C3: 100nF; C_0805_2012Metric; Manufacturer_Part_Number 478-KGM21NR71H104KTCT-ND
C4: 4u7, 250V; CP_Elec_10x10.5; Manufacturer_Part_Number AEH10104R7M250R
C5: 10uF; C_1206_3216Metric; Manufacturer_Part_Number CL31A106KBHNNNE
C6: 100nF, 250V; C_1812_4532Metric; Manufacturer_Part_Number CC1812KKX7RYBB104
D1: ES2F; DIOM5436X244N; Manufacturer_Part_Number 625-ES2F-E3; Mouser Part Number 625-ES2F-E3
H1, H2, H3, H4, H5, H6, H7: MouseBites; Mousebites; not fitted
H8, H9, H10, H11, H12, H13, H14, H15, H16, H17, H18, H19, H20, H21: MountingHole; MountingHole_3.2mm_M3; not fitted
J1, J2, J8, J9, J10, J11, J12: Conn_01x02; PinSocket_1x04_P2.54mm_Vertical; not fitted
J7: Conn_01x02; PinHeader_1x05_P2.54mm_Vertical; not fitted
L1: 100uH; CDRH125101MC; Manufacturer_Part_Number CDRH125/LDNP-101MC
Microcontroller1: Conn_01x08; XIAO-nRF52840-DIP; not fitted
Power_In1, Power_In2: Conn_01x07; PinSocket_1x02_P2.54mm_Vertical; not fitted
R1: 8k; R_0805_2012Metric; Manufacturer_Part_Number P0805Z8001FNT
R2: 1M6; R_0805_2012Metric_Pad1.20x1.40mm_HandSolder; Manufacturer_Part_Number KTR10EZPF1604
R3, R4, R8, R11: 22M; R_1206_3216Metric; Manufacturer_Part_Number RMCF1206JT22M0
R5: 10k; R_0805_2012Metric; Manufacturer_Part_Number CRCW080510K0FKEA
RSENSE1: 0R100; R_2010_5025Metric; Manufacturer_Part_Number WSL2010R1000FEA18
R_pot_sub1: 0 Ohms; R_0805_2012Metric; not fitted
SW2: SW_SPDT; PinHeader_1x03_P2.54mm_Vertical; not fitted
T1: TK560P60Y; TO-220-3_Vertical; Manufacturer_Part_Number IRF644PBF-ND
U1: MAX1771ESA; PowerIntegrations_PDIP-8; Manufacturer_Part_Number MAX1771CPA
U2: HV513; SOP-24_7.5x15.4mm_P1.27mm; Manufacturer_Part_Number HV513WG-G
U3: Power Pad; TestPoint_Pad_D2.0mm; not fitted
U4, U11, U12, U13, U14: Electrode 2; Electrode; not fitted
U5: Electrode 3; Electrode; not fitted
U6: On Pad; TestPoint_Pad_D2.0mm; not fitted
U7: Ground Ref; TestPoint_Pad_D2.0mm; not fitted
U8: Electrode 6; Electrode; not fitted
U9, U23, U24, U25: Electrode 2; Electrode_6_2; not fitted
U10: Electrode 8; Electrode; not fitted
U15, U16, U17, U18: Electrode 2; Electrode_3; not fitted
U19, U20, U21, U22: Electrode 2; Electrode_4; not fitted
U26: MCP41050; SOIC-8_3.9x4.9mm_P1.27mm; Manufacturer_Part_Number MCP41050T-I/SN
U27, U28, U29, U30: Electrode 2; Electrode_5; not fitted
U31, U32, U33, U34: Electrode 2; Electrode_6; not fitted
U35: Test Pad; TestPoint_Pad_D3.0mm; not fitted

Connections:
+3.3V: Microcontroller1.12, U2.2 (VDD_logic_supply), U26.8 (VDD)
+5V: Microcontroller1.14, Power_In2.1
BL: U2.4 (BL), U2.5 (POL), U35.1
DIN: Microcontroller1.4, U2.10 (DIN)
GND: C1.2, C2.2, C3.2, C4.2, C5.2, C6.2, Microcontroller1.13, Power_In1.2, Power_In2.2, R3.2, R4.2, R5.1, R8.2, R11.2, RSENSE1.2, R_pot_sub1.2, U1.4 (SHDN), U1.6 (AGND), U1.7 (GND), U2.11 (LVGND), U2.13 (HVGND), U2.14 (HVGND), U7.1, U26.4 (VSS), U26.7 (PB0)
HV13_Clk: Microcontroller1.6, U2.6 (CLK)
LE: Microcontroller1.2, R5.2, U2.7 (LE)
unnamed: J1.1, U10.1
unnamed: J1.2, U8.1
unnamed: J1.3, U5.1
unnamed: J1.4, U4.1
unnamed: J2.1, R3.1, U2.22 (HVOUT8)
unnamed: J2.2, R4.1, U2.20 (HVOUT6)
unnamed: J2.3, R8.1, U2.17 (HVOUT3)
unnamed: J2.4, R11.1, U2.15 (HVOUT1)
unnamed: J7.1, U14.1
unnamed: J7.2, U13.1
unnamed: J7.4, U12.1
unnamed: J7.5, U11.1
unnamed: J8.1, U18.1
unnamed: J8.2, U17.1
unnamed: J8.3, U16.1
unnamed: J8.4, U15.1
unnamed: J9.1, U22.1
unnamed: J9.2, U21.1
unnamed: J9.3, U20.1
unnamed: J9.4, U19.1
unnamed: J10.1, U25.1
unnamed: J10.2, U24.1
unnamed: J10.3, U9.1
unnamed: J10.4, U23.1
unnamed: J11.1, U30.1
unnamed: J11.2, U29.1
unnamed: J11.3, U28.1
unnamed: J11.4, U27.1
unnamed: J12.1, U34.1
unnamed: J12.2, U33.1
unnamed: J12.3, U32.1
unnamed: J12.4, U31.1
unnamed: C1.1, C2.1, C5.1, L1.1, SW2.1 (A), U1.2 (VCC), U3.1
unnamed: D1.2, L1.2, T1.2 (D)
unnamed: T1.1 (G), U1.1 (EXT), U6.1
unnamed: RSENSE1.1, T1.3 (S), U1.8 (CS)
unnamed: R1.2, R2.2, U1.3 (FB)
unnamed: C3.1, U1.5 (REF)
unnamed: R1.1, R_pot_sub1.1, U26.5 (PA0), U26.6 (PW0)
Pot_CS: Microcontroller1.10, U26.1 (~CS)
Pot_Clk: Microcontroller1.9, U26.2 (SCK)
Pot_SI: Microcontroller1.11, U26.3 (SI)
V_HV: C4.1, C6.1, D1.1, R2.1, U2.23 (HVpp), U2.24 (HVpp)
V_In: Power_In1.1, SW2.2 (B), SW2.3 (C)

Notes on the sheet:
HIGH VOLTAGE CONTROL
Note: requires 50 V to function
ELECTRODES
HIGH VOLTAGE BOOST CONVERTER
Note: can connect both inputs if using 4.5 V to 5 V input
R1 + R_Potentiometer = Ra Should be 8 kOhm to 58 kOhm.
VOUT = 1.5 x (R2/Ra +1) = 42 V to 302 V
CONTROLLER CONNECTIONS
VOLTAGE INPUT (5 V to 12 V)

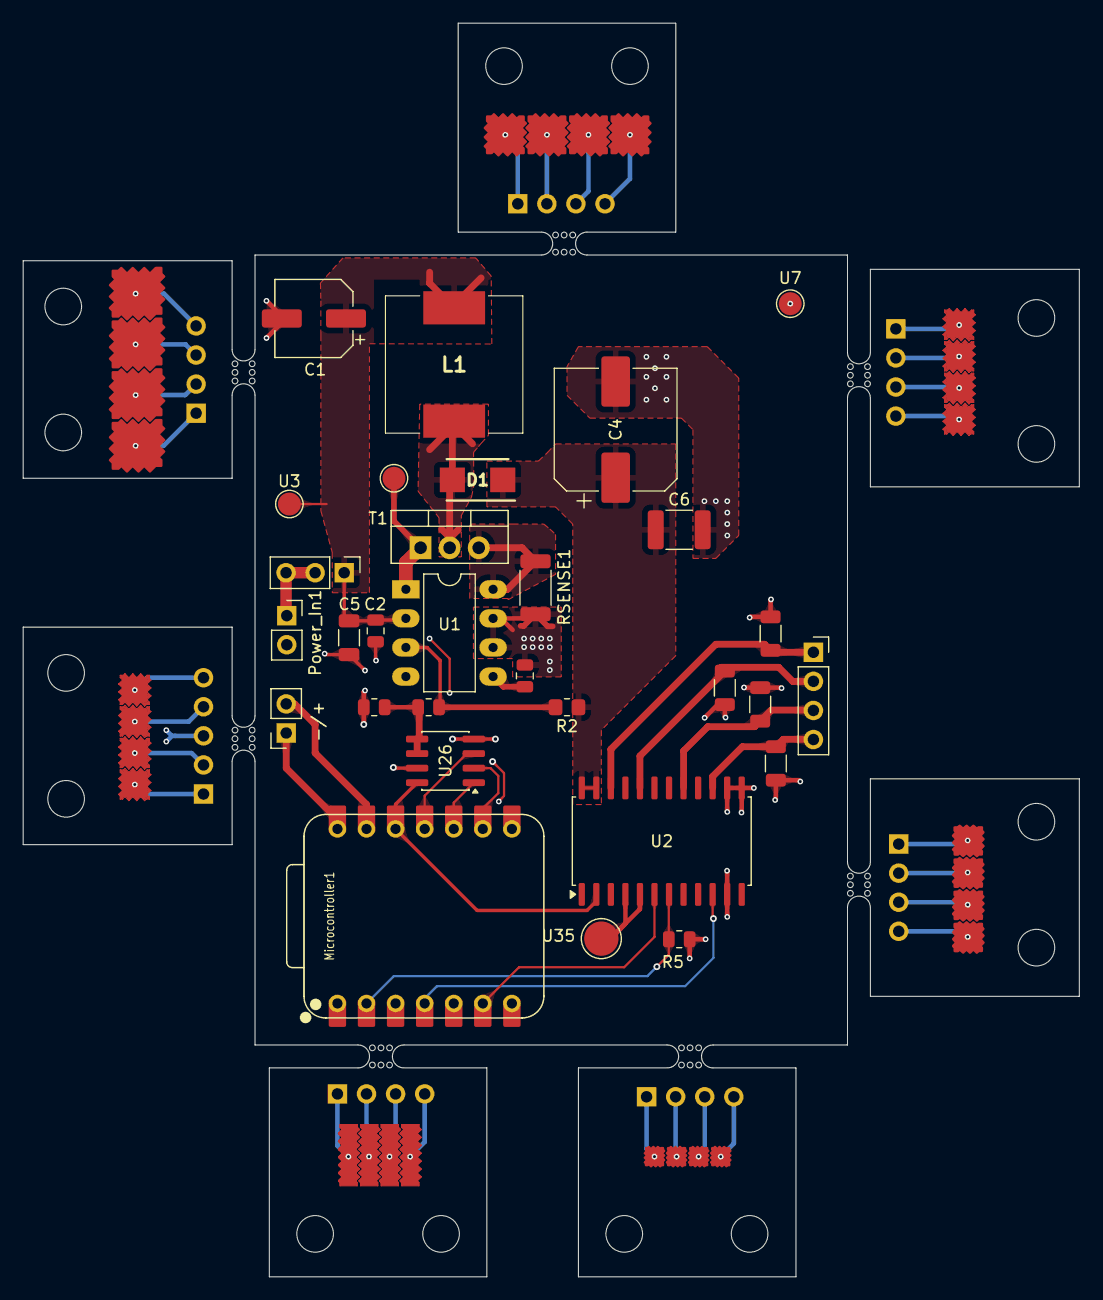
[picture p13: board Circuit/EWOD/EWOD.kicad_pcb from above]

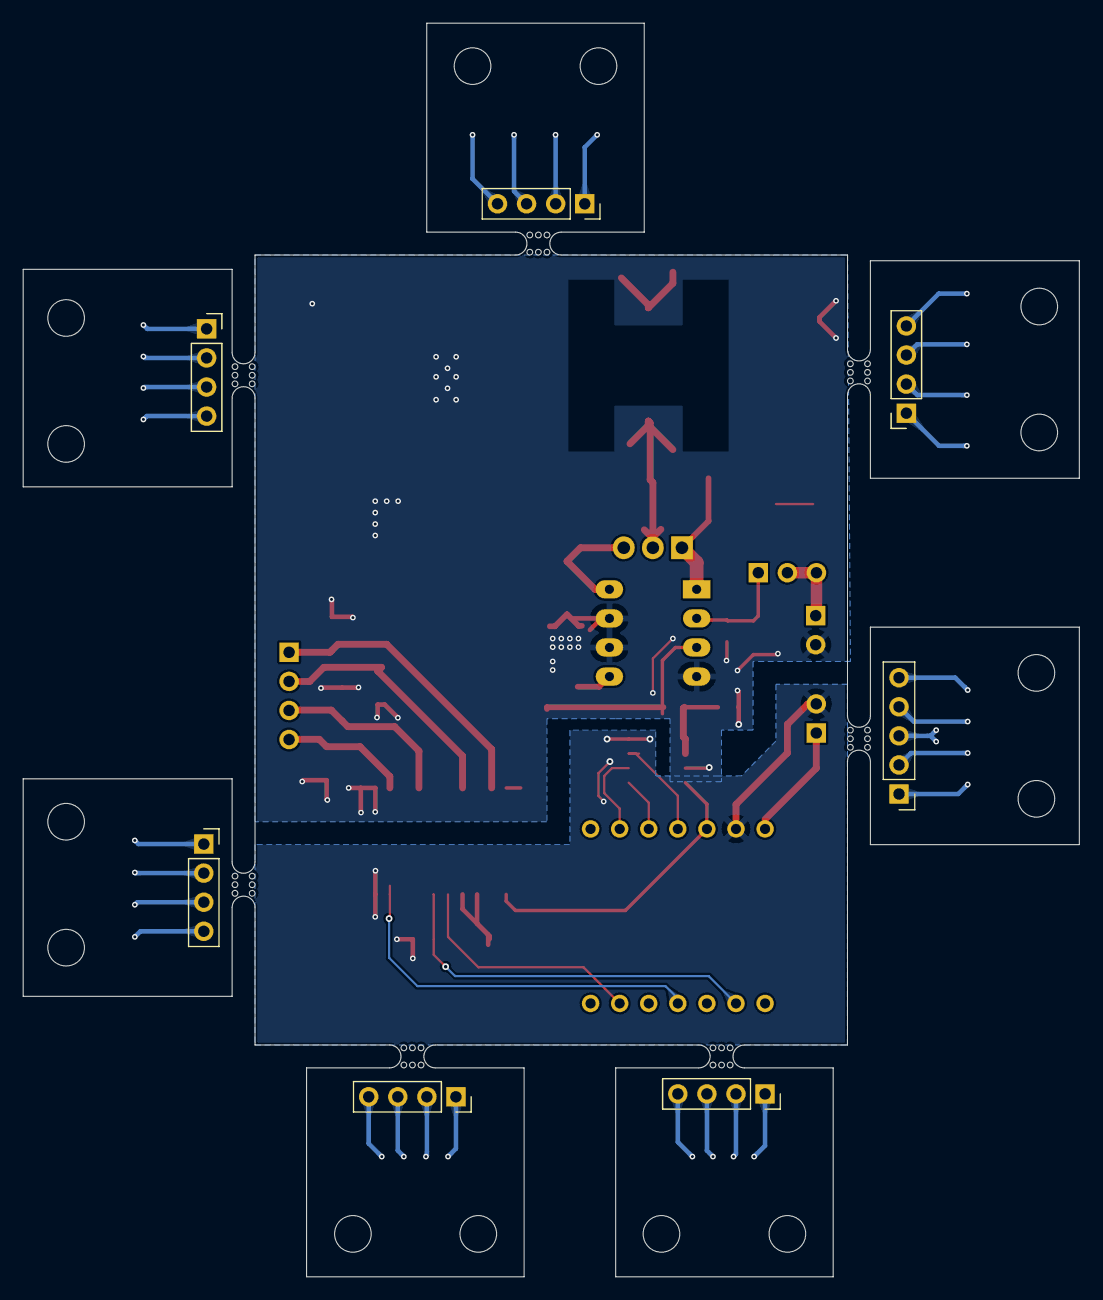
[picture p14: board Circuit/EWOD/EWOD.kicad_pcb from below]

Board: 2 copper layers, 92.2 x 109.5 mm, 86 parts (7 on the bottom side), 51 nets.

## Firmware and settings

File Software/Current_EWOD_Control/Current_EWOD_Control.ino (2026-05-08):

#include <SPI.h>

// Startup delay before anything happens (milliseconds)
#define STARTUP_DELAY_MS 30000  

// Delay between each HV513 output step (milliseconds)
#define HV_STEP_DELAY_MS 1000   

// MCP41050 potentiometer value (0–255)
// 0   = minimum wiper position
// 255 = maximum wiper position
#define POT_VALUE 255           

// Optional: delay after setting potentiometer (milliseconds)
#define POST_POT_DELAY_MS 2000  

// HV513
#define HV_DIN  MOSI
#define HV_CLK  SCK
#define HV_LE   D5   // latch enable

// MCP41050 digital potentiometer
#define MCP_CS  D9   // chip select

// =========================
// SPI settings
// =========================
const uint32_t SPI_HZ = 1000000;

// =========================
// HV513 sequence
// 8 -> 6 -> 3 -> 1 -> 3 -> 6 -> repeat
// =========================
const uint8_t SEQ[] = {
  0x80, // HVOUT8
  0x20, // HVOUT6
  0x04, // HVOUT3
  0x01, // HVOUT1
  0x04, // HVOUT3
  0x20  // HVOUT6
};
const size_t SEQ_LEN = sizeof(SEQ) / sizeof(SEQ[0]);

// =========================
// MCP41050 write
// =========================
static void mcp41050_write(uint8_t value) {
  const uint8_t CMD_WRITE_POT0 = 0x11;

  digitalWrite(MCP_CS, LOW);

  SPI.beginTransaction(SPISettings(SPI_HZ, MSBFIRST, SPI_MODE0));
  SPI.transfer(CMD_WRITE_POT0);
  SPI.transfer(value);
  SPI.endTransaction();

  digitalWrite(MCP_CS, HIGH);
}

// =========================
// HV513 helpers
// =========================
static inline void hv513_latch() {
  digitalWrite(HV_LE, HIGH);
  delayMicroseconds(1);
  digitalWrite(HV_LE, LOW);
}

static void hv513_writeByte(uint8_t data) {
  // Ensure MCP is not selected
  digitalWrite(MCP_CS, HIGH);

  SPI.beginTransaction(SPISettings(SPI_HZ, MSBFIRST, SPI_MODE0));
  SPI.transfer(data);
  SPI.endTransaction();

  hv513_latch();
}

// =========================
// Init
// =========================
static void initPins() {
  pinMode(HV_LE, OUTPUT);
  digitalWrite(HV_LE, LOW);

  pinMode(MCP_CS, OUTPUT);
  digitalWrite(MCP_CS, HIGH);  // deselect pot

  SPI.begin();
}

// =========================
// Setup
// =========================
void setup() {
  initPins();

  // Start with all HV outputs low
  hv513_writeByte(0x00);

  // 1) Startup delay
  delay(STARTUP_DELAY_MS);

  // 2) Set potentiometer once
  mcp41050_write(POT_VALUE);

  // 3) Wait after setting pot
  delay(POST_POT_DELAY_MS);
}

// =========================
// Loop
// =========================
void loop() {
  static size_t idx = 0;

  hv513_writeByte(SEQ[idx]);
  delay(HV_STEP_DELAY_MS);

  idx++;
  if (idx >= SEQ_LEN) idx = 0;
}

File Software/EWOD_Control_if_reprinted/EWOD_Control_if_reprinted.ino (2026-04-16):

#include <SPI.h>

// XIAO nRF52840 pinout

// HV513 
//   LE   -> D1
//   CLK  -> D5
//   DIN  -> D3

#define HV_LE    D1
#define HV_CLK   D5
#define HV_DIN   D3

// MCP41050 (hardware SPI)
//   SCK  -> D8
//   CS   -> D9
//   SI   -> D10

#define MCP_SCK  D8
#define MCP_CS   D9
#define MCP_SI   D10

const uint32_t SPI_HZ = 1000000;
const uint32_t HV_STEP_DELAY_MS = 1000;

// HV513 test output pattern:
// HVOUT8 -> HVOUT6 -> HVOUT3 -> HVOUT1 -> HVOUT3 -> HVOUT6 -> repeat
const uint8_t SEQ[] = {
  0x80, // HVOUT8
  0x20, // HVOUT6
  0x04, // HVOUT3
  0x01, // HVOUT1
  0x04, // HVOUT3
  0x20  // HVOUT6
};

const size_t SEQ_LEN = sizeof(SEQ) / sizeof(SEQ[0]);

uint8_t hvState = 0x00;

// Write raw input to potentiometer via SPI
void potWriteRaw(uint8_t rawValue) {
  const uint8_t CMD_WRITE_POT0 = 0x11;

  digitalWrite(MCP_CS, LOW);
  SPI.beginTransaction(SPISettings(SPI_HZ, MSBFIRST, SPI_MODE0));
  SPI.transfer(CMD_WRITE_POT0);
  SPI.transfer(rawValue);
  SPI.endTransaction();
  digitalWrite(MCP_CS, HIGH);
}

// Converts target voltage input to raw potentiometer 255 to 0 value, sent to the pot
// note 255 is minimum resistance (0 Ohms), 0 is maximum (50 kOhms ideal) 
uint8_t voltageToPotRaw(float targetVoltage) {
  const float R2 = 1620000.0f;
  const float R1_FIXED = 8200.0f;
  const float RPOT_MAX = 50000.0f;

  if (targetVoltage < 43.25f) targetVoltage = 43.25f;
  if (targetVoltage > 297.84f) targetVoltage = 297.84f;

  float denominator = (targetVoltage / 1.5f) - 1.0f;
  float R1 = R2 / denominator;
  float Rpot = R1 - R1_FIXED;

  if (Rpot < 0.0f) Rpot = 0.0f;
  if (Rpot > RPOT_MAX) Rpot = RPOT_MAX;

  float rawFloat = 255.0f - (255.0f * Rpot / RPOT_MAX);
  int rawInt = (int)(rawFloat + 0.5f);

  if (rawInt < 0) rawInt = 0;
  if (rawInt > 255) rawInt = 255;

  return (uint8_t)rawInt;
}

// Function wrapper
void potWriteVoltage(float targetVoltage) {
  potWriteRaw(voltageToPotRaw(targetVoltage));
}

void hvLatch() {
  digitalWrite(HV_LE, HIGH);
  delayMicroseconds(1);
  digitalWrite(HV_LE, LOW);
}

void writeHVState() {
  for (int bitIndex = 7; bitIndex >= 0; bitIndex--) {
    digitalWrite(HV_CLK, LOW);
    digitalWrite(HV_DIN, (hvState >> bitIndex) & 0x01);
    delayMicroseconds(1);
    digitalWrite(HV_CLK, HIGH);
    delayMicroseconds(1);
  }

  digitalWrite(HV_CLK, LOW);
  hvLatch();
}

void clearAllOutputs() {
  hvState = 0x00;
  writeHVState();
}

// Write HVOUT high for HV513
void setOutputHigh(uint8_t outputNumber) {
  if (outputNumber < 1 || outputNumber > 8) return;
  hvState |= (1 << (outputNumber - 1));
  writeHVState();
}

// Write HVOUT low for HV513
void setOutputLow(uint8_t outputNumber) {
  if (outputNumber < 1 || outputNumber > 8) return;
  hvState &= ~(1 << (outputNumber - 1));
  writeHVState();
}

void setup() {
  pinMode(HV_LE, OUTPUT);
  pinMode(HV_CLK, OUTPUT);
  pinMode(HV_DIN, OUTPUT);

  digitalWrite(HV_LE, LOW);
  digitalWrite(HV_CLK, LOW);
  digitalWrite(HV_DIN, LOW);

  pinMode(MCP_CS, OUTPUT);
  digitalWrite(MCP_CS, HIGH);

  // Hardware SPI uses MCP_SCK (D8) and MCP_SI (D10)
  SPI.begin();

  clearAllOutputs();

  // raw 255 = minimum pot resistance = maximum output voltage
  potWriteRaw(255);

  // Example:
  // potWriteVoltage(250.0f);
  // setOutputHigh(1);
  // setOutputLow(1);
}

void loop() {
  static size_t idx = 0;

  hvState = SEQ[idx];
  writeHVState();

  delay(HV_STEP_DELAY_MS);

  idx++;
  if (idx >= SEQ_LEN) idx = 0;
}

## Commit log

2026-04-16 Circuit files and some test results
    [Droplet Sims.xlsx, EWOD.csv, EWOD.kicad_pcb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]
2026-04-16 Software for EWOD Circuit with added Helper Functions
2026-05-08 General tidying: Added code from the current printed EWOD circuit board in case further work is done with it. Added license, updated some test files, updated the READ.me, and added the CST switch fil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
    [Droplet Sims.xlsx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]
